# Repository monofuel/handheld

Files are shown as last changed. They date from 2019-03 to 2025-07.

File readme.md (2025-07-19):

# 🎮 Portable Handheld

Portable retropie system inspired by the pocket pigrrl

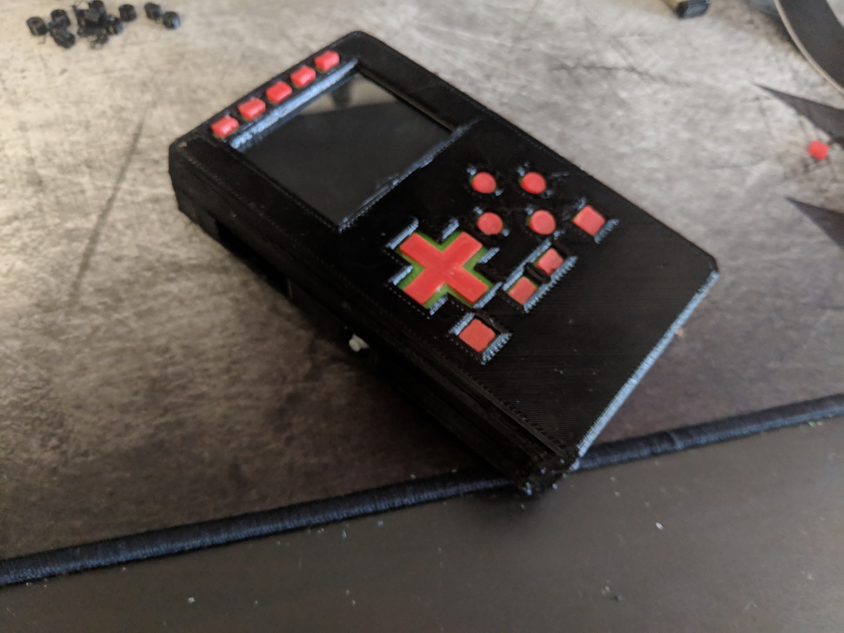
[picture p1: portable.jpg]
Portable


## 🎯 Design Goals
- ✅ must fit in pocket
- ✅ must be sturdy  
- ✅ expose audio and hdmi on side of case
- ✅ must be modular and easy to replace parts

## 🖨️ Printing Instructions
- 🚀 prototype STLs are available in the v0.9 folder (v1 is pending some improvements listed in `main.scad`)
- 📦 needs to be printed in 2 halves, a front half and back half.
  - 🚫 **no supports needed!**

- 🔧 print 10 `washer_4mm.stl` and 8 `washer_3mm.stl` (color does not matter, these are internal) if using `4-40 x 3/8"` screws (these were the screws I had on hand, and were recommended for the pigrrl 2)
  - I found the 4mm washers worked good on the screws on the rear of the case, and 3mm on the front.
  - there's probably room for improvement in using properly sized screws? but I can't be bothered when I only have 4-40 x 3/8, use whatever works for you.

### 📋 Detailed Printing Instructions

⚠️ **Make sure your printer is calibrated well!** 
🔗 https://www.thingiverse.com/thing:533472/files I recommend the negative space tolerance test.

#### 🧱 **PETG/PLA preferable:**
  - `front_case.stl`
  - `back_case.stl`

#### 🌊 **Flexible plastic:**
  - front buttons: **print both together!**
    - `front_buttons.stl`
    - `front_flex.stl`

## 🛒 Parts List

💰 Parts list comes to about **$120** of hardware from Adafruit, including the battery, sd card and pi.

### 🔧 Core Components
- 🥧 [Raspberry pi 3 A+](https://www.adafruit.com/product/4027)
- 📱 [Adafruit PITFT 2.4" touchscreen](https://www.adafruit.com/product/2455)
- 🔌 [26-pin cable](https://www.adafruit.com/product/862)
- 🔋 [powerboost 1000c](https://www.adafruit.com/product/2465)
  - 🚨 **no substitutes!**
  - 🔌 [decent power supply](https://www.adafruit.com/product/1995)

### 🔩 Hardware & Electronics
- 🔧 perfboard
- 🔩 [#4-40 3/8 screws](https://www.amazon.com/Machine-Screws-Phillips-Stainless-Quantity/dp/B01LY5VW6Q)
  - 🔄 possibly substitute with `M3` and modify screws in `main.scad`
  - ⚖️ depending on length, printed washer_4mm may not be needed
- 🔘 [slim tactile buttons](https://www.adafruit.com/product/1489) for PITFT
- 🎮 [soft tactile buttons](https://www.adafruit.com/product/3101)
  - 🔄 can substitute with [clicky switches](https://www.adafruit.com/product/367)
- 🔌 wires
- 💾 sd card, one big enough for all your games!
- 🔀 [slide switch](https://www.adafruit.com/product/805)
- 🔋 [3.7v 200mAh battery](https://www.adafruit.com/product/2011)

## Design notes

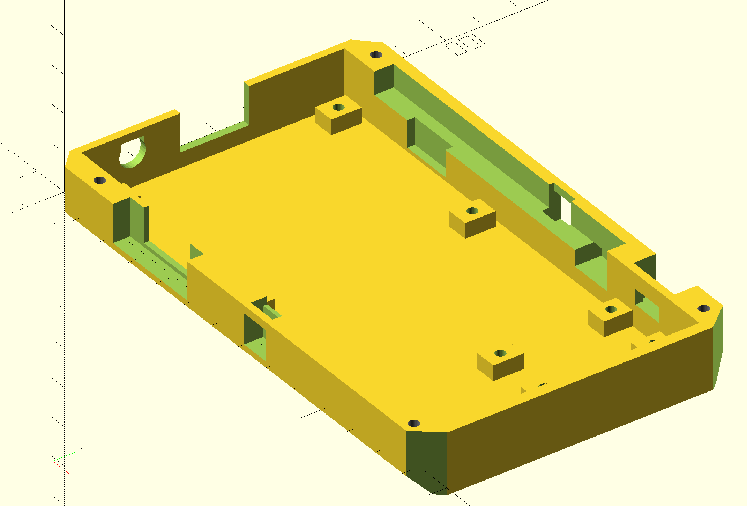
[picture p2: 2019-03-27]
photos/back_case-2.PNG

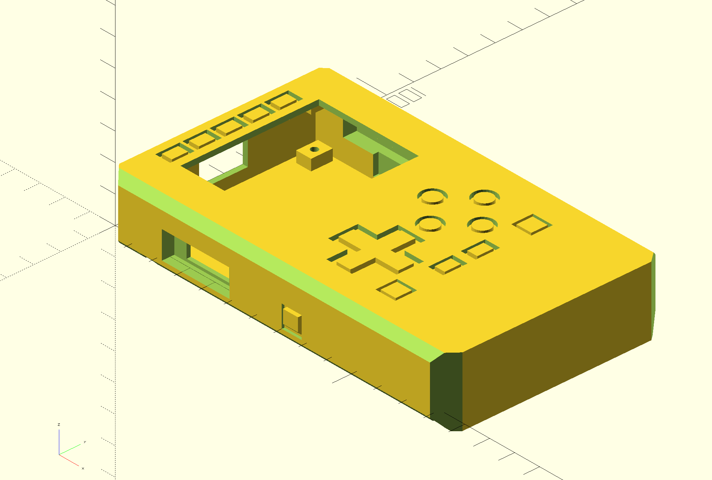
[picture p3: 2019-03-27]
photos/case_render.PNG

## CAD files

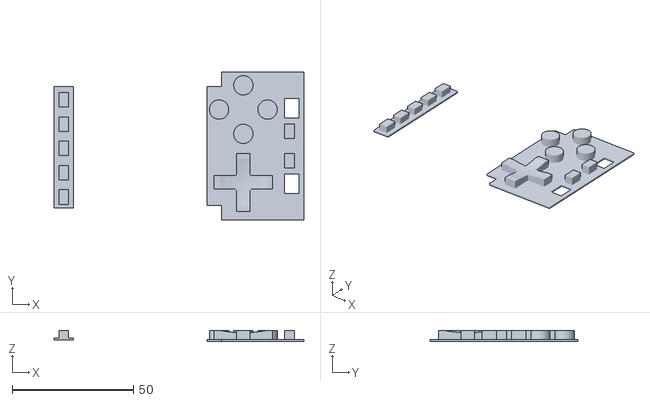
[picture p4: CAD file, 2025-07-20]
v1.00/front_flex.stl
103.0 x 61.0 x 4.50

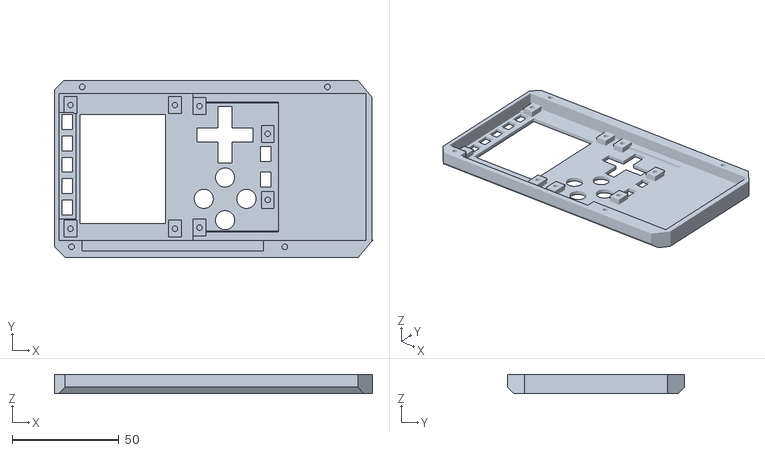
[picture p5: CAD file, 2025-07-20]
v1.00/front_case.stl
149.1 x 83.0 x 9.00

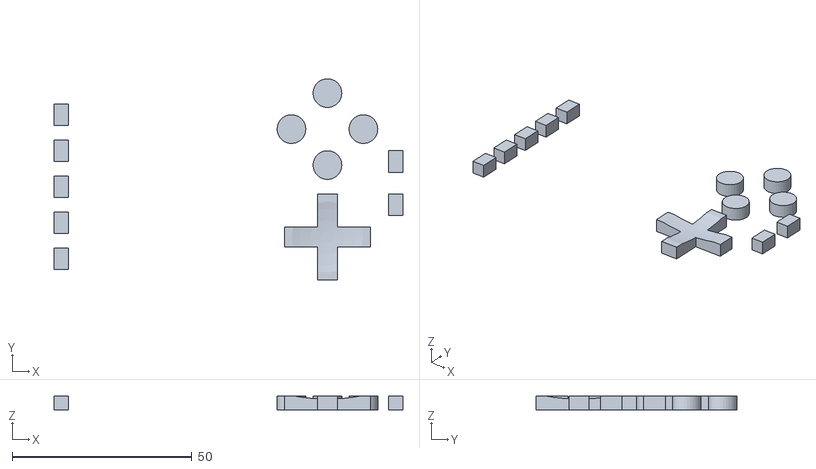
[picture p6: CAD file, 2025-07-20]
v1.00/front_buttons.stl
97.0 x 56.0 x 4.00

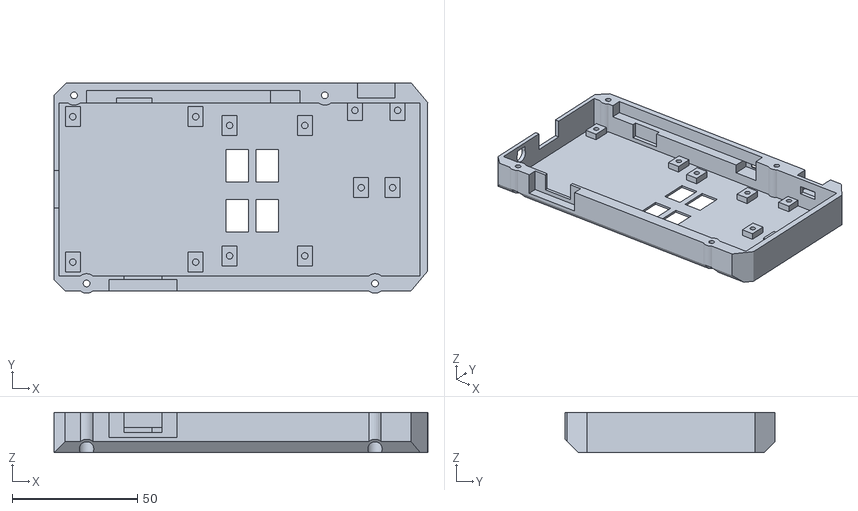
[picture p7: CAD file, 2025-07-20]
v1.00/back_case.stl
149.1 x 83.9 x 16.0

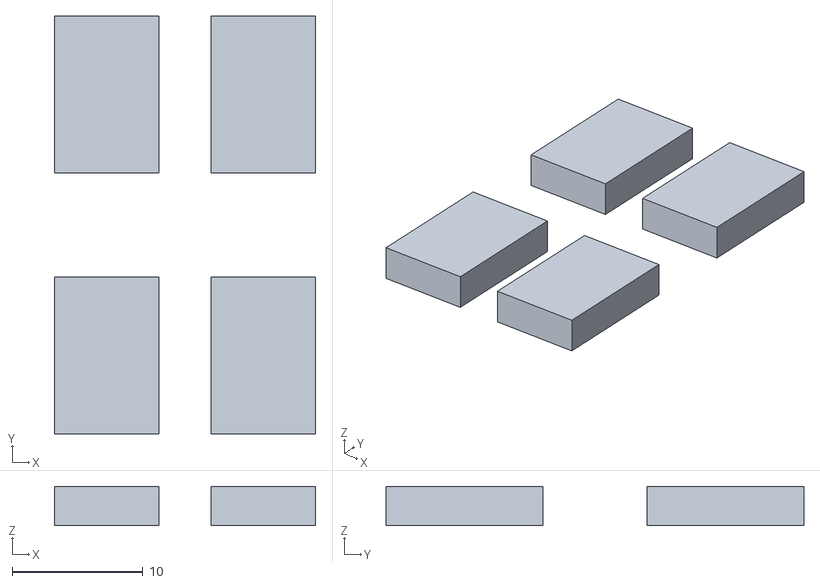
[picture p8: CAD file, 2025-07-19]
v1.00/back_buttons.stl
20.0 x 32.0 x 3.00

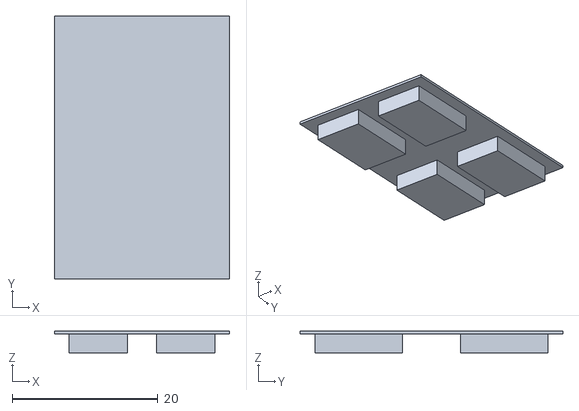
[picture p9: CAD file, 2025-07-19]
v1.00/back_flex.stl
24.0 x 36.0 x 3.00

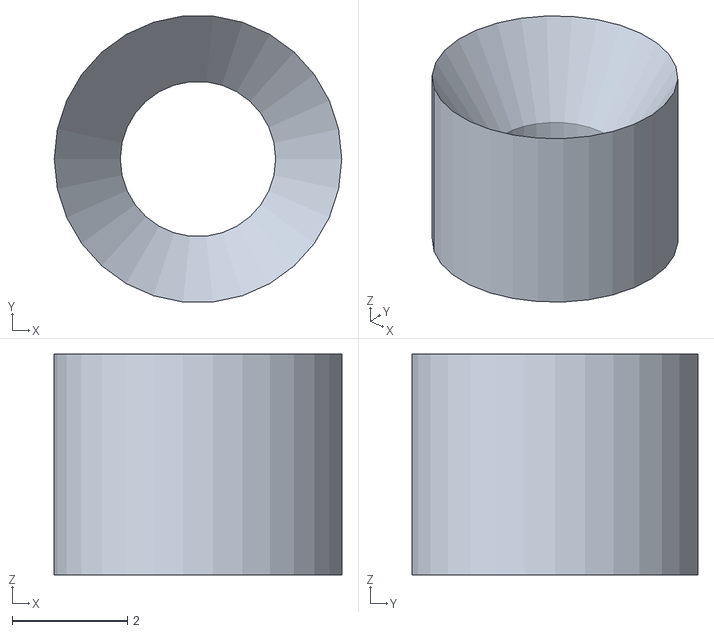
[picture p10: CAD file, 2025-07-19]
v1.00/washer_4mm.stl
5.00 x 4.97 x 3.84

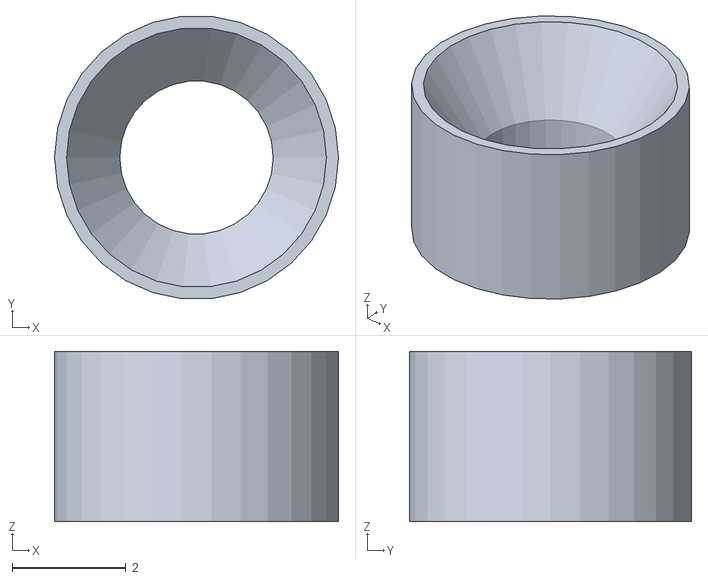
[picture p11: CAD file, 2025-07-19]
v1.00/washer_3mm.stl
5.00 x 4.97 x 3.00

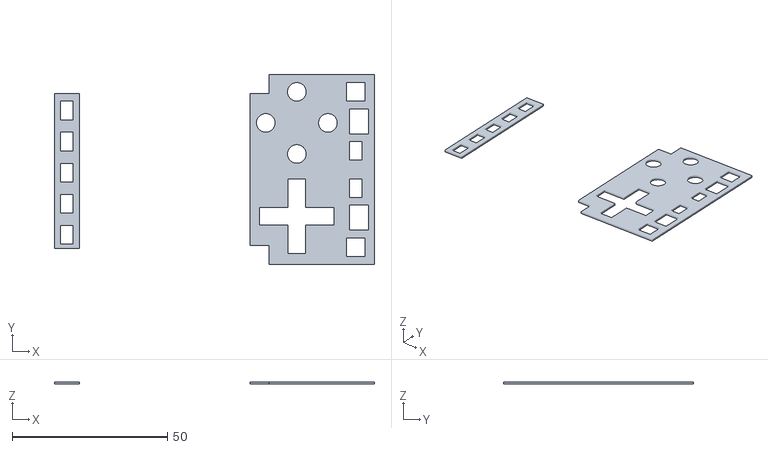
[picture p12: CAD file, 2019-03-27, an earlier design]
v0.9/front_flex.stl
103.0 x 61.0 x 0.8

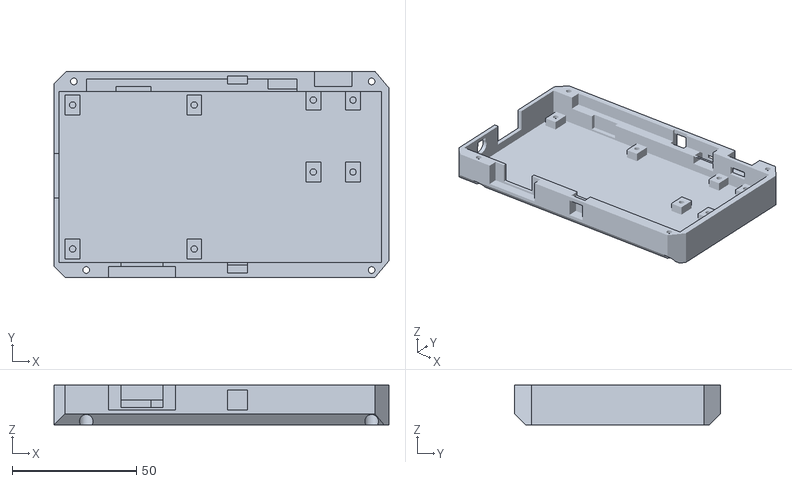
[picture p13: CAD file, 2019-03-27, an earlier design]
v0.9/back_case.stl
135.0 x 83.0 x 16.0

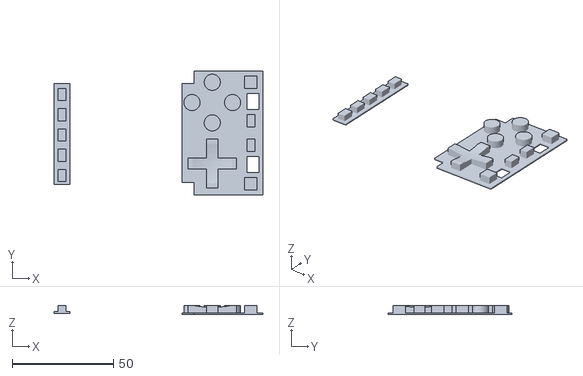
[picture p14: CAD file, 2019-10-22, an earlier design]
v0.95/front_flex.stl
103.0 x 61.0 x 4.50

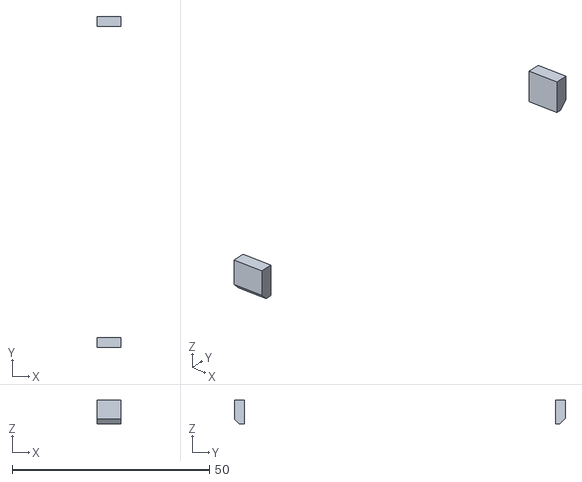
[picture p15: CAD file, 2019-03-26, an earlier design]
v0.9/MM_back_buttons.stl
6.00 x 84.0 x 6.00

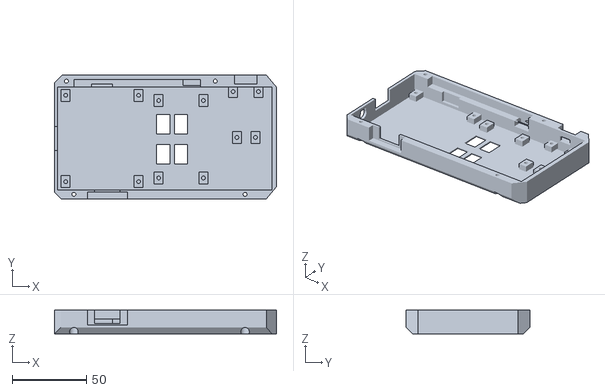
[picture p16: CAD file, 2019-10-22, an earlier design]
v0.95/back_case.stl
149.1 x 83.0 x 16.0

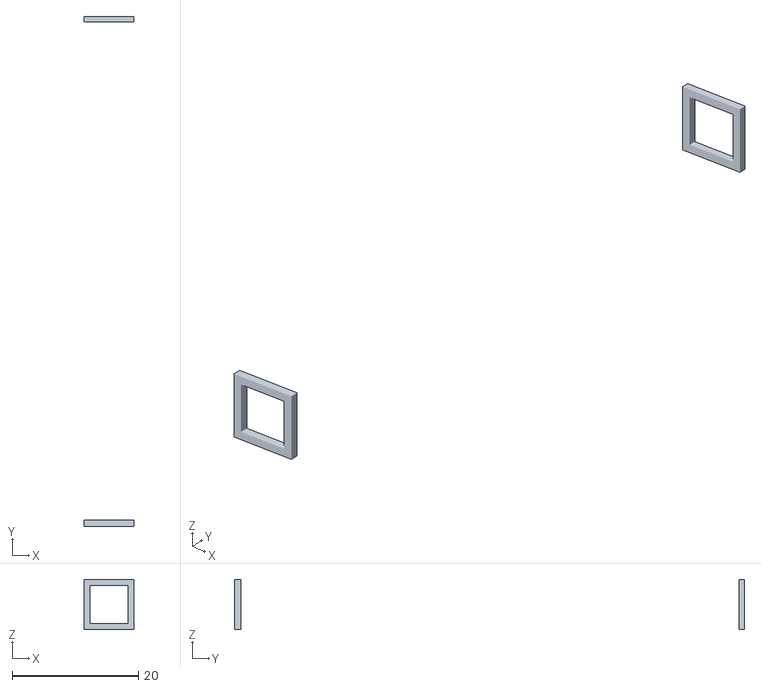
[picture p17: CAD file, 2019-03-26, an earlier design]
v0.9/MM_LR_flex.stl
8.00 x 80.9 x 8.00

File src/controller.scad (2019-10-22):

use <util.scad>;

module switches() {
	  translate([2.5*5,2.5,0])  switch();
		translate([2.5,2.5*5,0])  switch();
		translate([2.5*5,2.5*9,0])  switch();
		translate([2.5*9,2.5*5,0])  switch();
		
		translate([2.5*12,2.5,0])  switch();
		translate([2.5*12,2.5*9,0])  switch();
}

module controller() {
	
	// 59mm across
	// 35.6 long
	
	// 2.5 between buttons
	
	x  = 40;
	y = 62;
	z = 1.60;
	translate([0, 0, -z]) {
			color("green") linear_extrude(height=z)
				difference() {
					hull() {
						translate([  3,   3]) circle(r=3);
						translate([x-3,   3]) circle(r=3);
						translate([x-3, y-3]) circle(r=3);
						translate([  3, y-3]) circle(r=3);
					}
				}
		}
	   switches();
		
		translate([0,2.5*12,0])
			switches();
		
}

module back_controller() {
	x  = 40;
	y = 62;
	z = 1.60;
	translate([0, 0, -z]) {
		color("green") linear_extrude(height=z)
			difference() {
				hull() {
					translate([  3,   3]) circle(r=3);
					translate([x-3,   3]) circle(r=3);
					translate([x-3, y-3]) circle(r=3);
					translate([  3, y-3]) circle(r=3);
				}
			}
		rotate([0,180,0]) translate([-2.5*5,2.5*7,0])  switch();
		rotate([0,180,0]) translate([-2.5*10,2.5*7,0])  switch();

		rotate([0,180,0]) translate([-2.5*5,2.5*15,0])  switch();
		rotate([0,180,0]) translate([-2.5*10,2.5*15,0])  switch();
	}

}

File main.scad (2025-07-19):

// models for preview
use <src/pitft.scad>;
use <src/pi.scad>
use <src/controller.scad>;
use <src/util.scad>;

// printed parts
use <src/front_case.scad>;
use <src/front_flex.scad>;
use <src/front_buttons.scad>;
use <src/back_case.scad>;
use <src/back_flex.scad>;
use <src/back_buttons.scad>;

module handheld() {
    // hardware_front();
    hardware_back();
    // pitft_washers();
    // pi_washers();
    // front_case_flex();
    // back_case_flex();
    // beveled_front_case();
    beveled_back_case();
}
handheld();

// TODO

// the 2 powerboost 1000c screw posts on the right side of the case are good
// the 2 on the left side are not positioned properly

// some screw holes too close to edge of case

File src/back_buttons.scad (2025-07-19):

button_height = 3;

// I had extra GPIO pins on the back half and so added an extra L2 and R2
// IMPORTANT: these buttons have to line up with the switches on the perfboard, and on the pitft
// their locations can't move

module lr_button() {
    // L1, L2, R1, R2
    cube([8,12,button_height], center=false);
}
module lr_button_cutout() {
    // how much space to carve out of the case
    translate([-0.5,-0.5,0])
        cube([9,13,5], center=false);
}

module back_buttons() {
    // All 4 buttons are identical and symmetric
    // I don't really know which is which (doesn't really matter?)

    color("blue") {
        translate([0,0,0]) lr_button();
        translate([12,0,0]) lr_button();

        translate([0,20,0]) lr_button();
        translate([12,20,0]) lr_button();
    }
    
}

back_buttons();

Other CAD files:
v0.95/front_case.stl
v0.95/front_buttons.stl
v0.9/LR_button.stl
v0.95/back_buttons.stl
src/back_case.scad
src/back_flex.scad
src/front_buttons.scad
src/front_case.scad
src/front_flex.scad
src/pi.scad
src/pitft.scad
src/powerboost.scad
src/util.scad
src/washer_3mm.scad
src/washer_4mm.scad
v0.9/LR_flex.stl
v0.9/back_case.amf
v0.9/front_buttons.stl
v0.9/front_case.amf
v0.9/front_case.stl
v0.9/washer.stl
v0.9/washer_4mm.stl
v0.95/back_flex.stl

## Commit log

2019-03-26 add power switch
    [main.scad]
2019-03-26 fix d-pad
    [main.scad]
2019-03-26 add model
    [main.scad]
2019-03-26 add buttons
    [main.scad]
2019-03-26 add models
    [LR_button.stl, LR_flex.stl, MM_LR_flex.stl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]
2019-03-26 enable parts
    [main.scad]
2019-03-27 add notes
    [main.scad]
2019-03-27 move stls
    [LR_button.stl, LR_flex.stl, MM_LR_flex.stl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]
2019-03-27 enable all parts
    [main.scad]
2019-03-27 fix front flex
    [front_flex.stl, main.scad]
2019-03-27 add amf file
    [back_case.amf, front_case.amf]
2019-03-27 add comments
    [main.scad]
2019-03-27 add comment
    [main.scad]
2019-08-24 single material progress
    [back_buttons.scad, back_case.scad, front_case.scad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]
2019-08-24 adjust pitft buttons
    [front_buttons.scad, front_buttons.stl, front_case.scad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]
2019-08-24 adjust buttons
    [front_buttons.scad, front_case.scad, front_flex.scad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]
2019-08-25 add back buttons
    [back_buttons.scad, back_case.scad, back_flex.scad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]
2025-07-19 remove note on LR buttons
2025-07-19 make ports more snug
    [back_case.scad, main.scad]
2025-07-19 adjust power switch cutout
    [back_case.scad, main.scad]
2025-07-19 make power switch hole a touch biger for it to move easier
    [back_case.scad]
2025-07-19 nudge screw holes to reduce print artifacts from thin walls
    [back_case.scad, front_case.scad, main.scad]
2025-07-19 add both washer varients
    [back_buttons.stl, back_case.stl, back_flex.stl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]
2025-07-19 flip case for building
    [front_case.scad, front_case.stl, front_flex.stl]
2025-07-20 final v1.0 tweaks FINAL FINAL FINAL
    [back_case.scad, back_case.stl, front_buttons.stl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]
